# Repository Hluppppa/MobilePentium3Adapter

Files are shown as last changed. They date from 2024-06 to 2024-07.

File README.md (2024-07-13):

# Mobile Pentium 3 Adapter
An attempt to recreate an adapter for Pentium 3 mobile processors to socket 370 (bga495 -> pga370) by reverse engineering existed one.
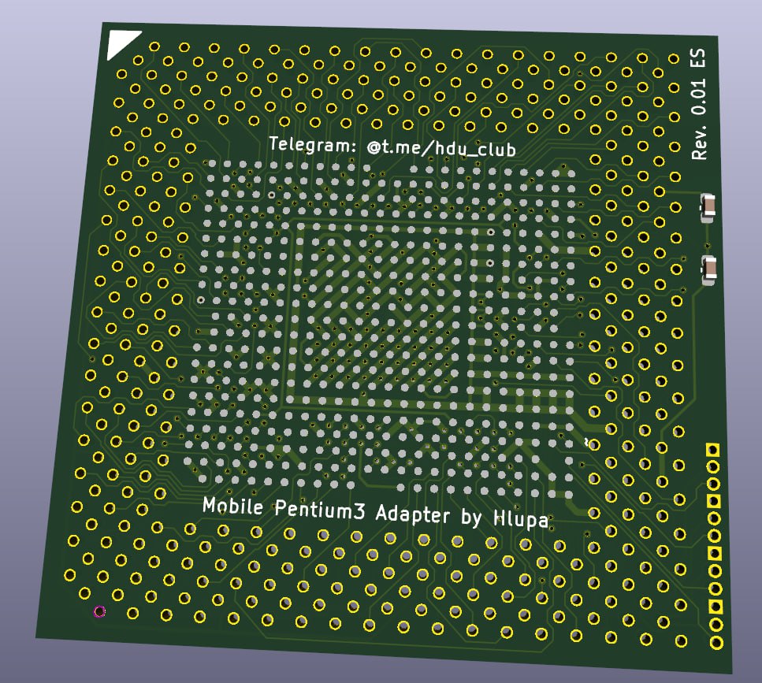
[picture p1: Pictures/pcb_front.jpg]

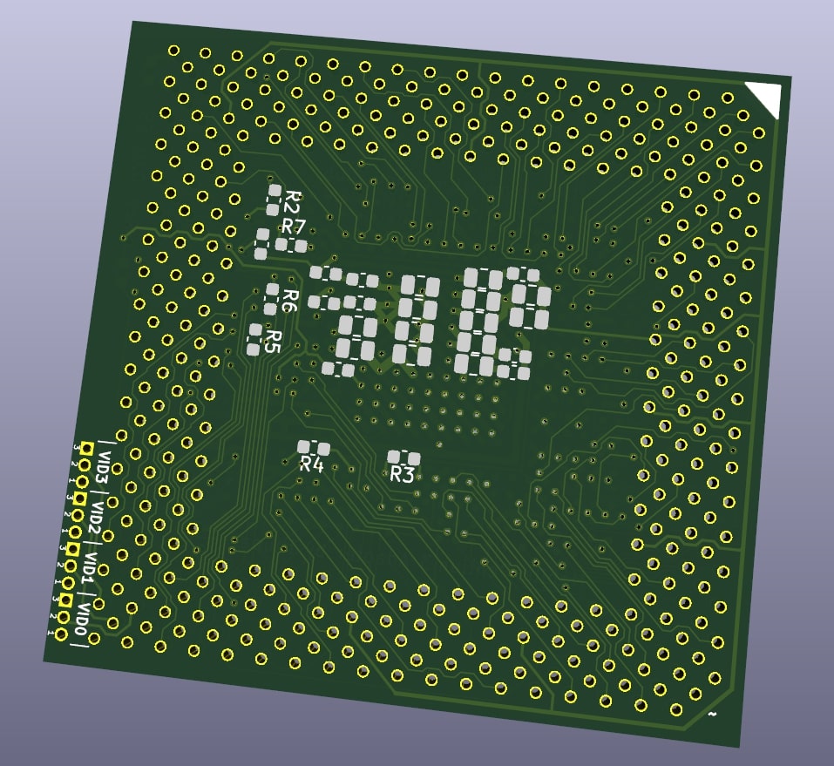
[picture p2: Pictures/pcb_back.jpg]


Now you can install XBOX-Original's CPU in normal desktop :D

Core Voltage (VCC) table:
| VID3 | VID2 | VID1 | VID0 | VCC  |
| ----| ----| ----| ----| ---- |
| 1-2 | 1-2 | 1-2 | 1-2 | 1.30 |
| 1-2 | 1-2 | 1-2 | 2-3 | 1.35 |
| 1-2 | 1-2 | 2-3 | 1-2 | 1.40 |
| 1-2 | 1-2 | 2-3 | 2-3 | 1.45 |
| 1-2 | 2-3 | 1-2 | 1-2 | 1.50 |
| 1-2 | 2-3 | 1-2 | 2-3 | 1.55 |
| 1-2 | 2-3 | 2-3 | 1-2 | 1.60 |
| 1-2 | 2-3 | 2-3 | 2-3 | 1.65 |
| 2-3 | 1-2 | 1-2 | 1-2 | 1.70 |
| 2-3 | 1-2 | 1-2 | 2-3 | 1.75 |
| 2-3 | 1-2 | 2-3 | 1-2 | 1.80 |
| 2-3 | 1-2 | 2-3 | 2-3 | 1.85 |
| 2-3 | 2-3 | 1-2 | 1-2 | 1.90 |
| 2-3 | 2-3 | 1-2 | 2-3 | 1.95 |
| 2-3 | 2-3 | 2-3 | 1-2 | 2.00 |
| 2-3 | 2-3 | 2-3 | 2-3 | 2.05 |

ATTENTION! This adapter is still in development and has not been tested yet!

Made with KiCad 12.05.2024

Links:

https://download.intel.com/design/PentiumIII/datashts/24526408.pdf

https://datasheet.octopart.com/KC80526LY500256SL4JP-Intel-datasheet-125284.pdf

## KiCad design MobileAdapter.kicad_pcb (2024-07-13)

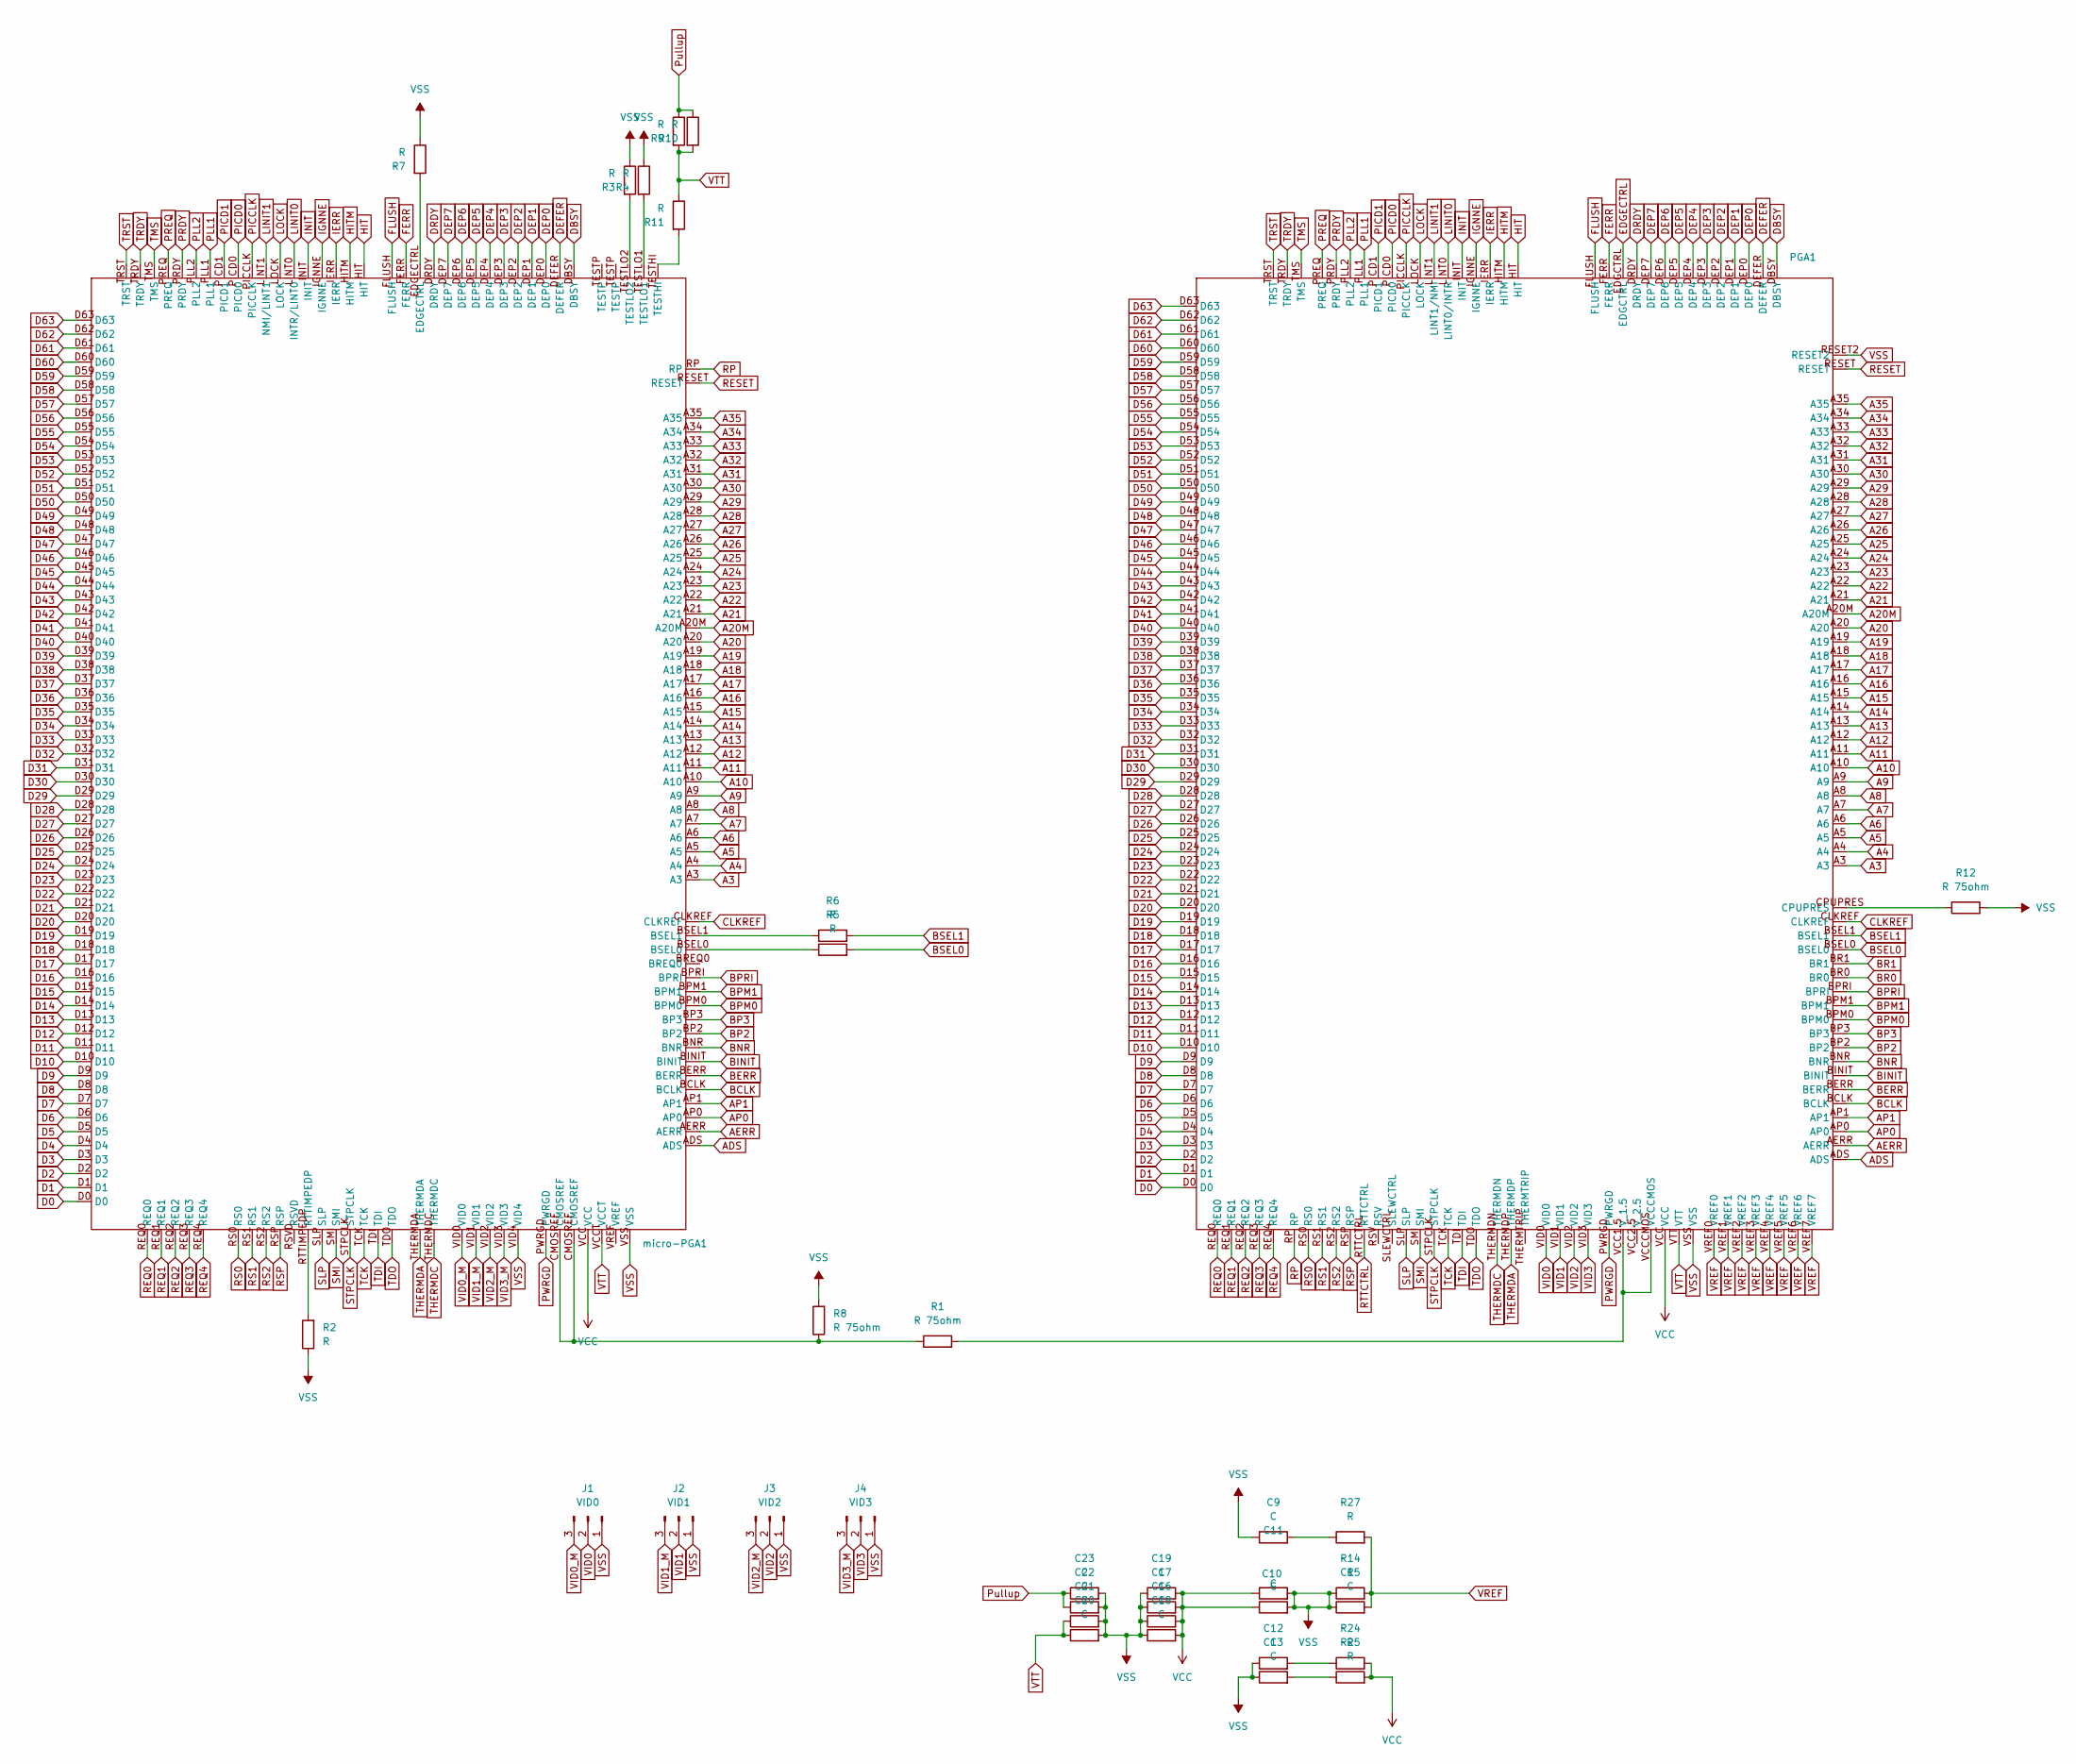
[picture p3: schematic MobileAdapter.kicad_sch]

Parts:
C9, C10, C11, C12, C13, C15, C16, C17, C18, C19, C20, C21: C; C_0805_2012Metric
C22, C23: C; C_0603_1608Metric
J1: VID0; PinHeader_1x03_P1.27mm_Vertical
J2: VID1; PinHeader_1x03_P1.27mm_Vertical
J3: VID2; PinHeader_1x03_P1.27mm_Vertical
J4: VID3; PinHeader_1x03_P1.27mm_Vertical
PGA1: pga370
R1, R8, R12: R 75ohm; C_0603_1608Metric
R2, R3, R4, R5, R6, R7, R9, R10, R11, R24, R25, R27: R; C_0603_1608Metric
R14: R; C_0805_2012Metric
micro-PGA1: bga495

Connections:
A3: PGA1.A3, micro-PGA1.A3
A4: PGA1.A4, micro-PGA1.A4
A5: PGA1.A5, micro-PGA1.A5
A6: PGA1.A6, micro-PGA1.A6
A7: PGA1.A7, micro-PGA1.A7
A8: PGA1.A8, micro-PGA1.A8
A9: PGA1.A9, micro-PGA1.A9
A10: PGA1.A10, micro-PGA1.A10
A11: PGA1.A11, micro-PGA1.A11
A12: PGA1.A12, micro-PGA1.A12
A13: PGA1.A13, micro-PGA1.A13
A14: PGA1.A14, micro-PGA1.A14
A15: PGA1.A15, micro-PGA1.A15
A16: PGA1.A16, micro-PGA1.A16
A17: PGA1.A17, micro-PGA1.A17
A18: PGA1.A18, micro-PGA1.A18
A19: PGA1.A19, micro-PGA1.A19
A20: PGA1.A20, micro-PGA1.A20
A20M: PGA1.A20M, micro-PGA1.A20M
A21: PGA1.A21, micro-PGA1.A21
A22: PGA1.A22, micro-PGA1.A22
A23: PGA1.A23, micro-PGA1.A23
A24: PGA1.A24, micro-PGA1.A24
A25: PGA1.A25, micro-PGA1.A25
A26: PGA1.A26, micro-PGA1.A26
A27: PGA1.A27, micro-PGA1.A27
A28: PGA1.A28, micro-PGA1.A28
A29: PGA1.A29, micro-PGA1.A29
A30: PGA1.A30, micro-PGA1.A30
A31: PGA1.A31, micro-PGA1.A31
A32: PGA1.A32, micro-PGA1.A32
A33: PGA1.A33, micro-PGA1.A33
A34: PGA1.A34, micro-PGA1.A34
A35: PGA1.A35, micro-PGA1.A35
ADS: PGA1.ADS, micro-PGA1.ADS
AERR: PGA1.AERR, micro-PGA1.AERR
AP0: PGA1.AP0, micro-PGA1.AP0
AP1: PGA1.AP1, micro-PGA1.AP1
BCLK: PGA1.BCLK, micro-PGA1.BCLK
BERR: PGA1.BERR, micro-PGA1.BERR
BINIT: PGA1.BINIT, micro-PGA1.BINIT
BNR: PGA1.BNR, micro-PGA1.BNR
BP2: PGA1.BP2, micro-PGA1.BP2
BP3: PGA1.BP3, micro-PGA1.BP3
BPM0: PGA1.BPM0, micro-PGA1.BPM0
BPM1: PGA1.BPM1, micro-PGA1.BPM1
BPRI: PGA1.BPRI, micro-PGA1.BPRI
BR0: PGA1.BR0
BR1: PGA1.BR1
BSEL0: PGA1.BSEL0, R5.2
BSEL1: PGA1.BSEL1, R6.2
CLKREF: PGA1.CLKREF, micro-PGA1.CLKREF
D0: PGA1.D0, micro-PGA1.D0
D1: PGA1.D1, micro-PGA1.D1
D2: PGA1.D2, micro-PGA1.D2
D3: PGA1.D3, micro-PGA1.D3
D4: PGA1.D4, micro-PGA1.D4
D5: PGA1.D5, micro-PGA1.D5
D6: PGA1.D6, micro-PGA1.D6
D7: PGA1.D7, micro-PGA1.D7
D8: PGA1.D8, micro-PGA1.D8
D9: PGA1.D9, micro-PGA1.D9
D10: PGA1.D10, micro-PGA1.D10
D11: PGA1.D11, micro-PGA1.D11
D12: PGA1.D12, micro-PGA1.D12
D13: PGA1.D13, micro-PGA1.D13
D14: PGA1.D14, micro-PGA1.D14
D15: PGA1.D15, micro-PGA1.D15
D16: PGA1.D16, micro-PGA1.D16
D17: PGA1.D17, micro-PGA1.D17
D18: PGA1.D18, micro-PGA1.D18
D19: PGA1.D19, micro-PGA1.D19
D20: PGA1.D20, micro-PGA1.D20
D21: PGA1.D21, micro-PGA1.D21
D22: PGA1.D22, micro-PGA1.D22
D23: PGA1.D23, micro-PGA1.D23
D24: PGA1.D24, micro-PGA1.D24
D25: PGA1.D25, micro-PGA1.D25
D26: PGA1.D26, micro-PGA1.D26
D27: PGA1.D27, micro-PGA1.D27
D28: PGA1.D28, micro-PGA1.D28
D29: PGA1.D29, micro-PGA1.D29
D30: PGA1.D30, micro-PGA1.D30
D31: PGA1.D31, micro-PGA1.D31
D32: PGA1.D32, micro-PGA1.D32
D33: PGA1.D33, micro-PGA1.D33
D34: PGA1.D34, micro-PGA1.D34
D35: PGA1.D35, micro-PGA1.D35
D36: PGA1.D36, micro-PGA1.D36
D37: PGA1.D37, micro-PGA1.D37
D38: PGA1.D38, micro-PGA1.D38
D39: PGA1.D39, micro-PGA1.D39
D40: PGA1.D40, micro-PGA1.D40
D41: PGA1.D41, micro-PGA1.D41
D42: PGA1.D42, micro-PGA1.D42
D43: PGA1.D43, micro-PGA1.D43
D44: PGA1.D44, micro-PGA1.D44
D45: PGA1.D45, micro-PGA1.D45
D46: PGA1.D46, micro-PGA1.D46
D47: PGA1.D47, micro-PGA1.D47
D48: PGA1.D48, micro-PGA1.D48
D49: PGA1.D49, micro-PGA1.D49
D50: PGA1.D50, micro-PGA1.D50
D51: PGA1.D51, micro-PGA1.D51
D52: PGA1.D52, micro-PGA1.D52
D53: PGA1.D53, micro-PGA1.D53
D54: PGA1.D54, micro-PGA1.D54
D55: PGA1.D55, micro-PGA1.D55
D56: PGA1.D56, micro-PGA1.D56
D57: PGA1.D57, micro-PGA1.D57
D58: PGA1.D58, micro-PGA1.D58
D59: PGA1.D59, micro-PGA1.D59
D60: PGA1.D60, micro-PGA1.D60
D61: PGA1.D61, micro-PGA1.D61
D62: PGA1.D62, micro-PGA1.D62
D63: PGA1.D63, micro-PGA1.D63
DBSY: PGA1.DBSY, micro-PGA1.DBSY
DEFER: PGA1.DEFER, micro-PGA1.DEFER
DEP0: PGA1.DEP0, micro-PGA1.DEP0
DEP1: PGA1.DEP1, micro-PGA1.DEP1
DEP2: PGA1.DEP2, micro-PGA1.DEP2
DEP3: PGA1.DEP3, micro-PGA1.DEP3
DEP4: PGA1.DEP4, micro-PGA1.DEP4
DEP5: PGA1.DEP5, micro-PGA1.DEP5
DEP6: PGA1.DEP6, micro-PGA1.DEP6
DEP7: PGA1.DEP7, micro-PGA1.DEP7
DRDY: PGA1.DRDY, micro-PGA1.DRDY
EDGECTRL: PGA1.EDGCTRL
FERR: PGA1.FERR, micro-PGA1.FERR
FLUSH: PGA1.FLUSH, micro-PGA1.FLUSH
HIT: PGA1.HIT, micro-PGA1.HIT
HITM: PGA1.HITM, micro-PGA1.HITM
IERR: PGA1.IERR, micro-PGA1.IERR
IGNNE: PGA1.IGNNE, micro-PGA1.IGNNE
INIT: PGA1.INIT, micro-PGA1.INIT
LINIT0: PGA1.LINT0 (LINT0/INTR), micro-PGA1.LINT0 (INTR/LINT0)
LINIT1: PGA1.LINT1 (LINT1/NMI), micro-PGA1.LINT1 (NMI/LINT1)
LOCK: PGA1.LOCK, micro-PGA1.LOCK
unnamed: C9.2, R27.1
unnamed: C12.2, R24.1
unnamed: C13.2, R25.1
unnamed: PGA1.CPUPRES, R12.1
unnamed: PGA1.VCC1.5 (V_1.5), PGA1.VCCCMOS, R1.2
unnamed: R1.1, R8.1, micro-PGA1.CMOSREF
unnamed: R2.2, micro-PGA1.RTTIMPEDP
unnamed: R3.2, micro-PGA1.TESTLO2
unnamed: R4.2, micro-PGA1.TESTLO1
unnamed: R5.1, micro-PGA1.BSEL0
unnamed: R6.1, micro-PGA1.BSEL1
unnamed: R7.2, micro-PGA1.EDGECTRL
unnamed: R11.2, micro-PGA1.TESTHI
PICCLK: PGA1.PICCLK, micro-PGA1.PICCLK
PICD0: PGA1.PICD0, micro-PGA1.PICD0
PICD1: PGA1.PICD1, micro-PGA1.PICD1
PLL1: PGA1.PLL1, micro-PGA1.PLL1
PLL2: PGA1.PLL2, micro-PGA1.PLL2
PRDY: PGA1.PRDY, micro-PGA1.PRDY
PREQ: PGA1.PREQ, micro-PGA1.PREQ
PWRGD: PGA1.PWRGD, micro-PGA1.PWRGD
Pullup: C22.1, C23.1, R9.1, R10.1
REQ0: PGA1.REQ0, micro-PGA1.REQ0
REQ1: PGA1.REQ1, micro-PGA1.REQ1
REQ2: PGA1.REQ2, micro-PGA1.REQ2
REQ3: PGA1.REQ3, micro-PGA1.REQ3
REQ4: PGA1.REQ4, micro-PGA1.REQ4
RESET: PGA1.RESET, micro-PGA1.RESET
RP: PGA1.RP, micro-PGA1.RP
RS0: PGA1.RS0, micro-PGA1.RS0
RS1: PGA1.RS1, micro-PGA1.RS1
RS2: PGA1.RS2, micro-PGA1.RS2
RSP: PGA1.RSP, micro-PGA1.RSP
RTTCTRL: PGA1.RTTCTRL
SLP: PGA1.SLP, micro-PGA1.SLP
SMI: PGA1.SMI, micro-PGA1.SMI
STPCLK: PGA1.STPCLK, micro-PGA1.STPCLK
TCK: PGA1.TCK, micro-PGA1.TCK
TDI: PGA1.TDI, micro-PGA1.TDI
TDO: PGA1.TDO, micro-PGA1.TDO
THERMDA: PGA1.THERMDP, micro-PGA1.THERMDA
THERMDC: PGA1.THERMDN, micro-PGA1.THERMDC
TMS: PGA1.TMS, micro-PGA1.TMS
TRDY: PGA1.TRDY, micro-PGA1.TRDY
TRST: PGA1.TRST, micro-PGA1.TRST
VCC: C10.1, C11.1, C16.2, C17.2, C18.2, C19.2, PGA1.VCC, R24.2, R25.2, micro-PGA1.VCC
VID0: J1.2, PGA1.VID0
VID0_M: J1.3, micro-PGA1.VID0
VID1: J2.2, PGA1.VID1
VID1_M: J2.3, micro-PGA1.VID1
VID2: J3.2, PGA1.VID2
VID2_M: J3.3, micro-PGA1.VID2
VID3: J4.2, PGA1.VID3
VID3_M: J4.3, micro-PGA1.VID3
VREF: C15.2, PGA1.VREF0, PGA1.VREF1, PGA1.VREF2, PGA1.VREF3, PGA1.VREF4, PGA1.VREF5, PGA1.VREF6, PGA1.VREF7, R14.2, R27.2
VSS: C9.1, C10.2, C11.2, C12.1, C13.1, C15.1, C16.1, C17.1, C18.1, C19.1, C20.2, C21.2, C22.2, C23.2, J1.1, J2.1, J3.1, J4.1, PGA1.RESET2, PGA1.VSS, R2.1, R3.1, R4.1, R7.1, R8.2, R12.2, R14.1, micro-PGA1.VID4, micro-PGA1.VSS
VTT: C20.1, C21.1, PGA1.VTT, R9.2, R10.2, R11.1, micro-PGA1.VCCT

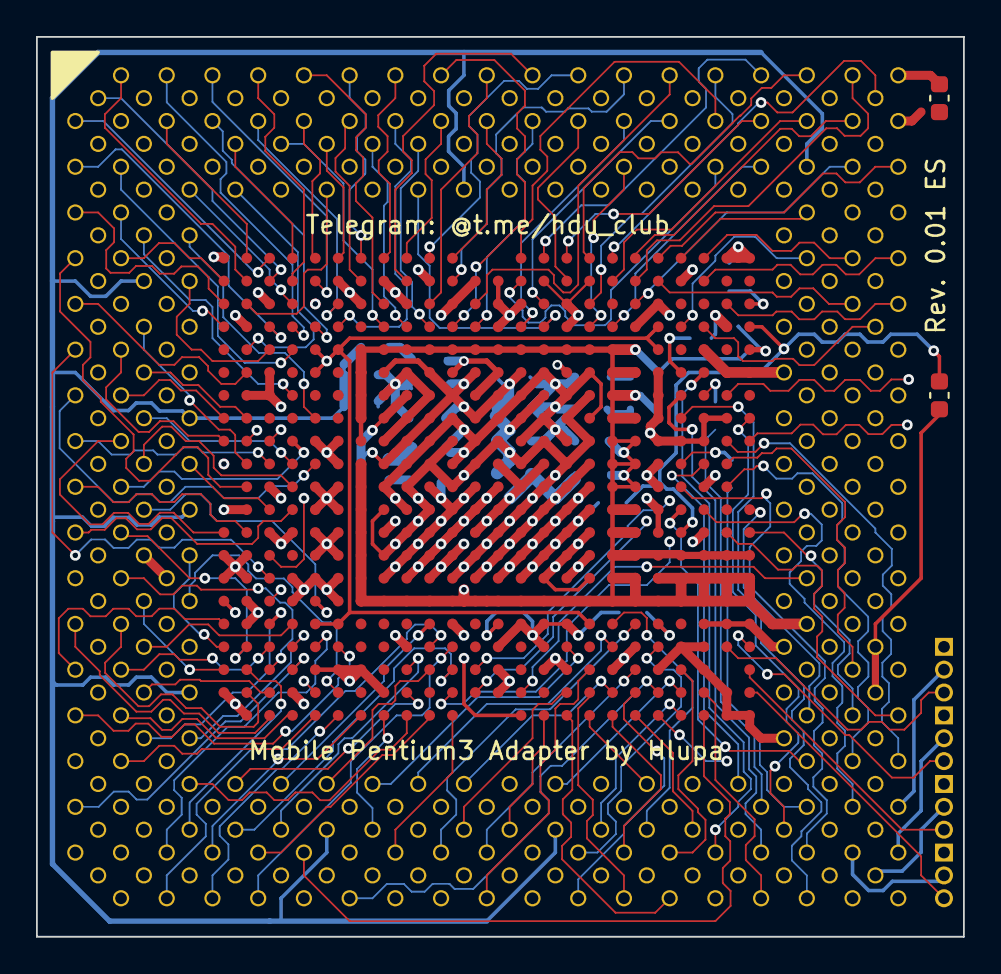
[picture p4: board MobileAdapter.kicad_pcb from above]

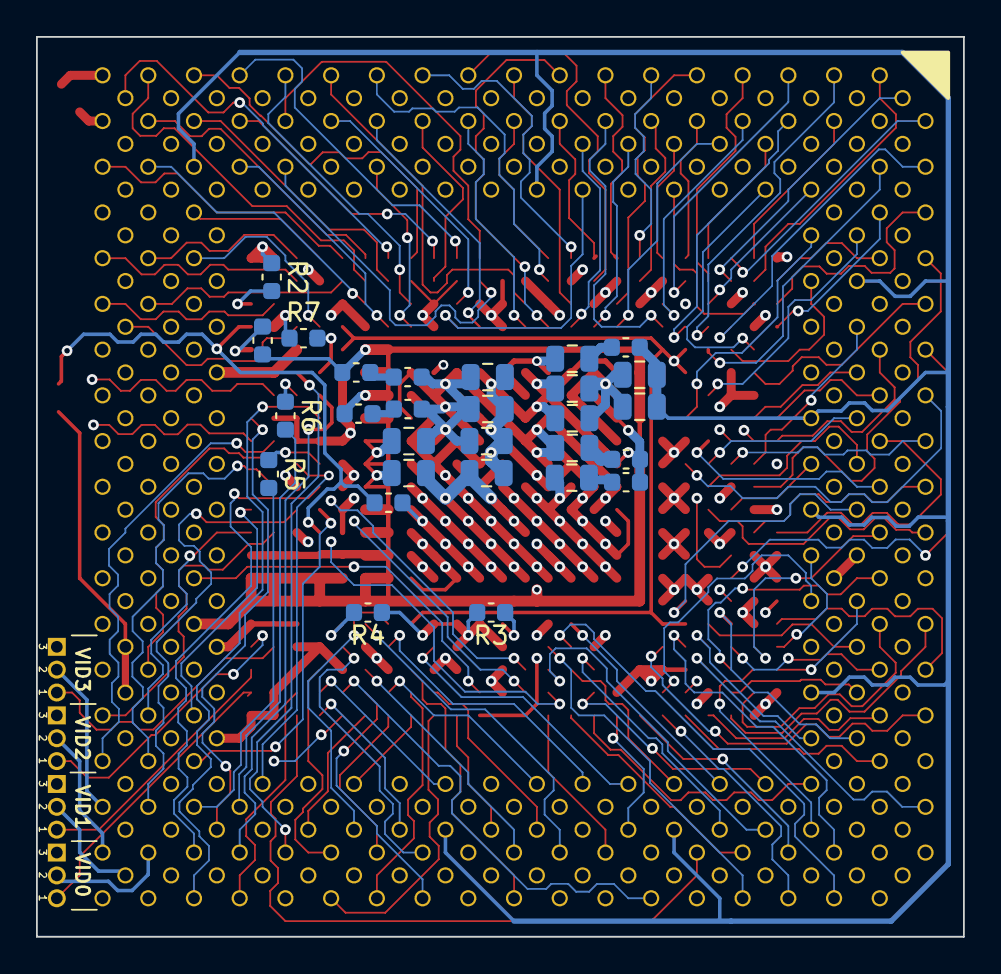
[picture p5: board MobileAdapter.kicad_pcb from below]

Board: 4 copper layers, 51.5 x 50.0 mm, 36 parts (29 on the bottom side), 191 nets.

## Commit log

2024-06-22 Adding GERBER file
    [MobileAdapter-B_Cu.gbr, MobileAdapter-B_Mask.gbr, MobileAdapter-B_Paste.gbr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]
2024-07-13 Trace and Silk fix
